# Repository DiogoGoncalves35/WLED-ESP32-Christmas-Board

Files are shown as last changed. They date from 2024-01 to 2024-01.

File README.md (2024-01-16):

# WLED ESP32 Christmas Board

  

This board is designed to control 4 x WS2812B string lights (Max 3A Total) via WLED software, and it was added a 4A fuse to protect. Max current for the 4 strings is about 3A, and 1A is left to ESP32.   



Board was tested with 2 x WS2812B 5 meter string lights, each draws arround 400-600 mA with color white and brightness at 100%. WLED version was [v0.14.0 "Hoshi"](https://github.com/Aircoookie/WLED/releases/tag/v0.14.0).

------------

### Schematic 

The [schematic](/PCB/Schematic.pdf) is arround ESP32 WROOM 32E microcontroller. A 4A fuse was added to protect the circuit in case of short circuit, the AMS1117 regulates the input voltage to 3.3V and powers the ESP32.

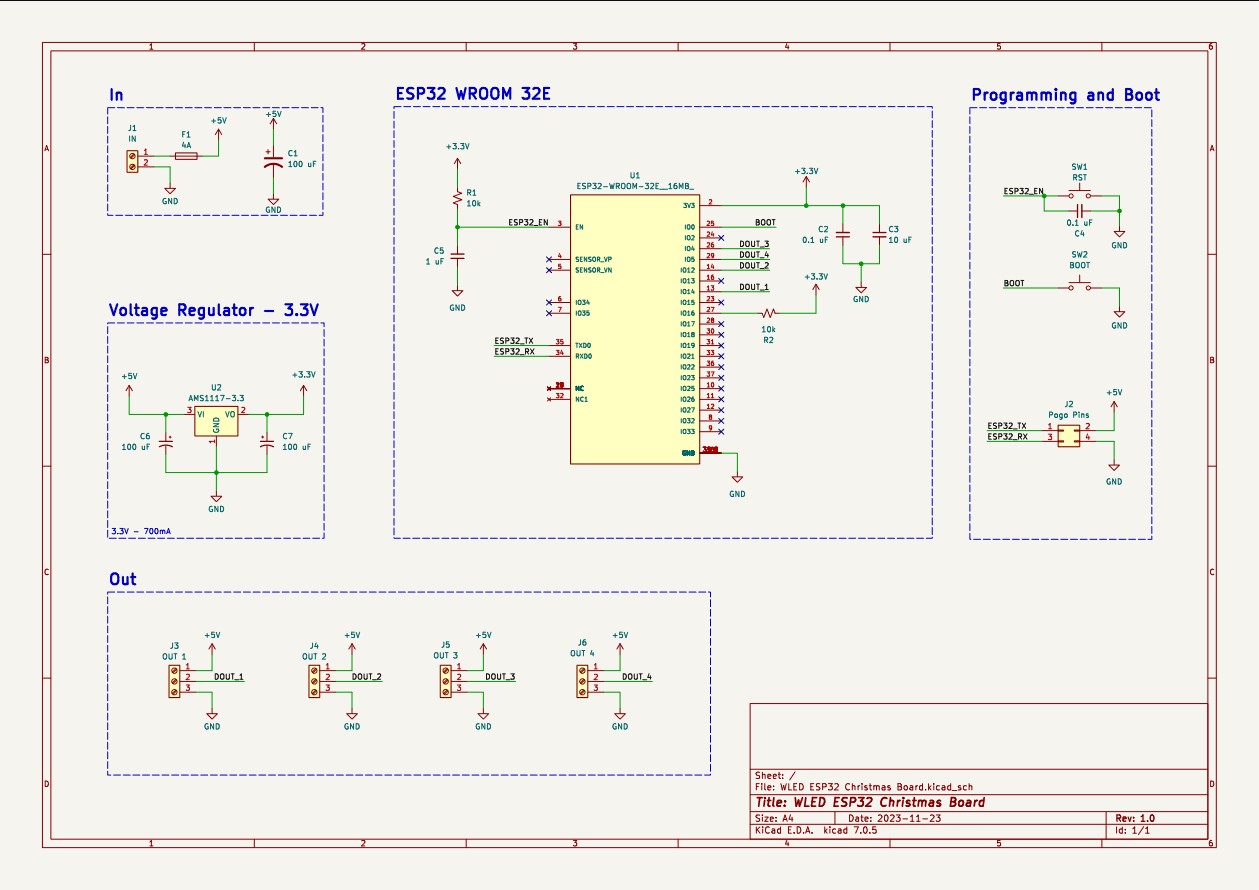
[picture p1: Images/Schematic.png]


------------

### PCB

[This](/PCB) 1.6mm board contains 4 layers with the stackup Signal+Power/GND/GND/Signal+Power.The connector on the right is for programming and it works with pogo pins.  

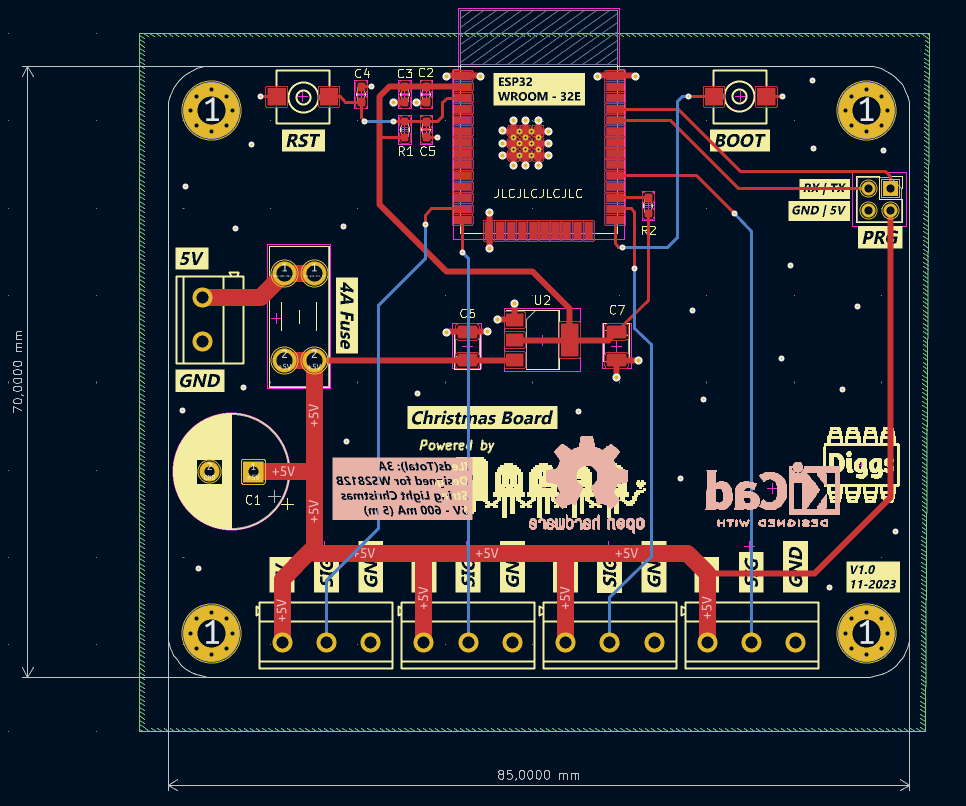
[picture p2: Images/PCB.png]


------------

### Known issues

- Some noise on TX/RX lines, sometimes [this](https://user-images.githubusercontent.com/64553282/108736433-e6be2380-7531-11eb-8186-5ca70f359cc5.PNG) appears and causes board to crash, by connecting pogo pins withot any connection to a programmer board fixed the issue

------------

### To-Do

- Fixing noise on TX/RX lines

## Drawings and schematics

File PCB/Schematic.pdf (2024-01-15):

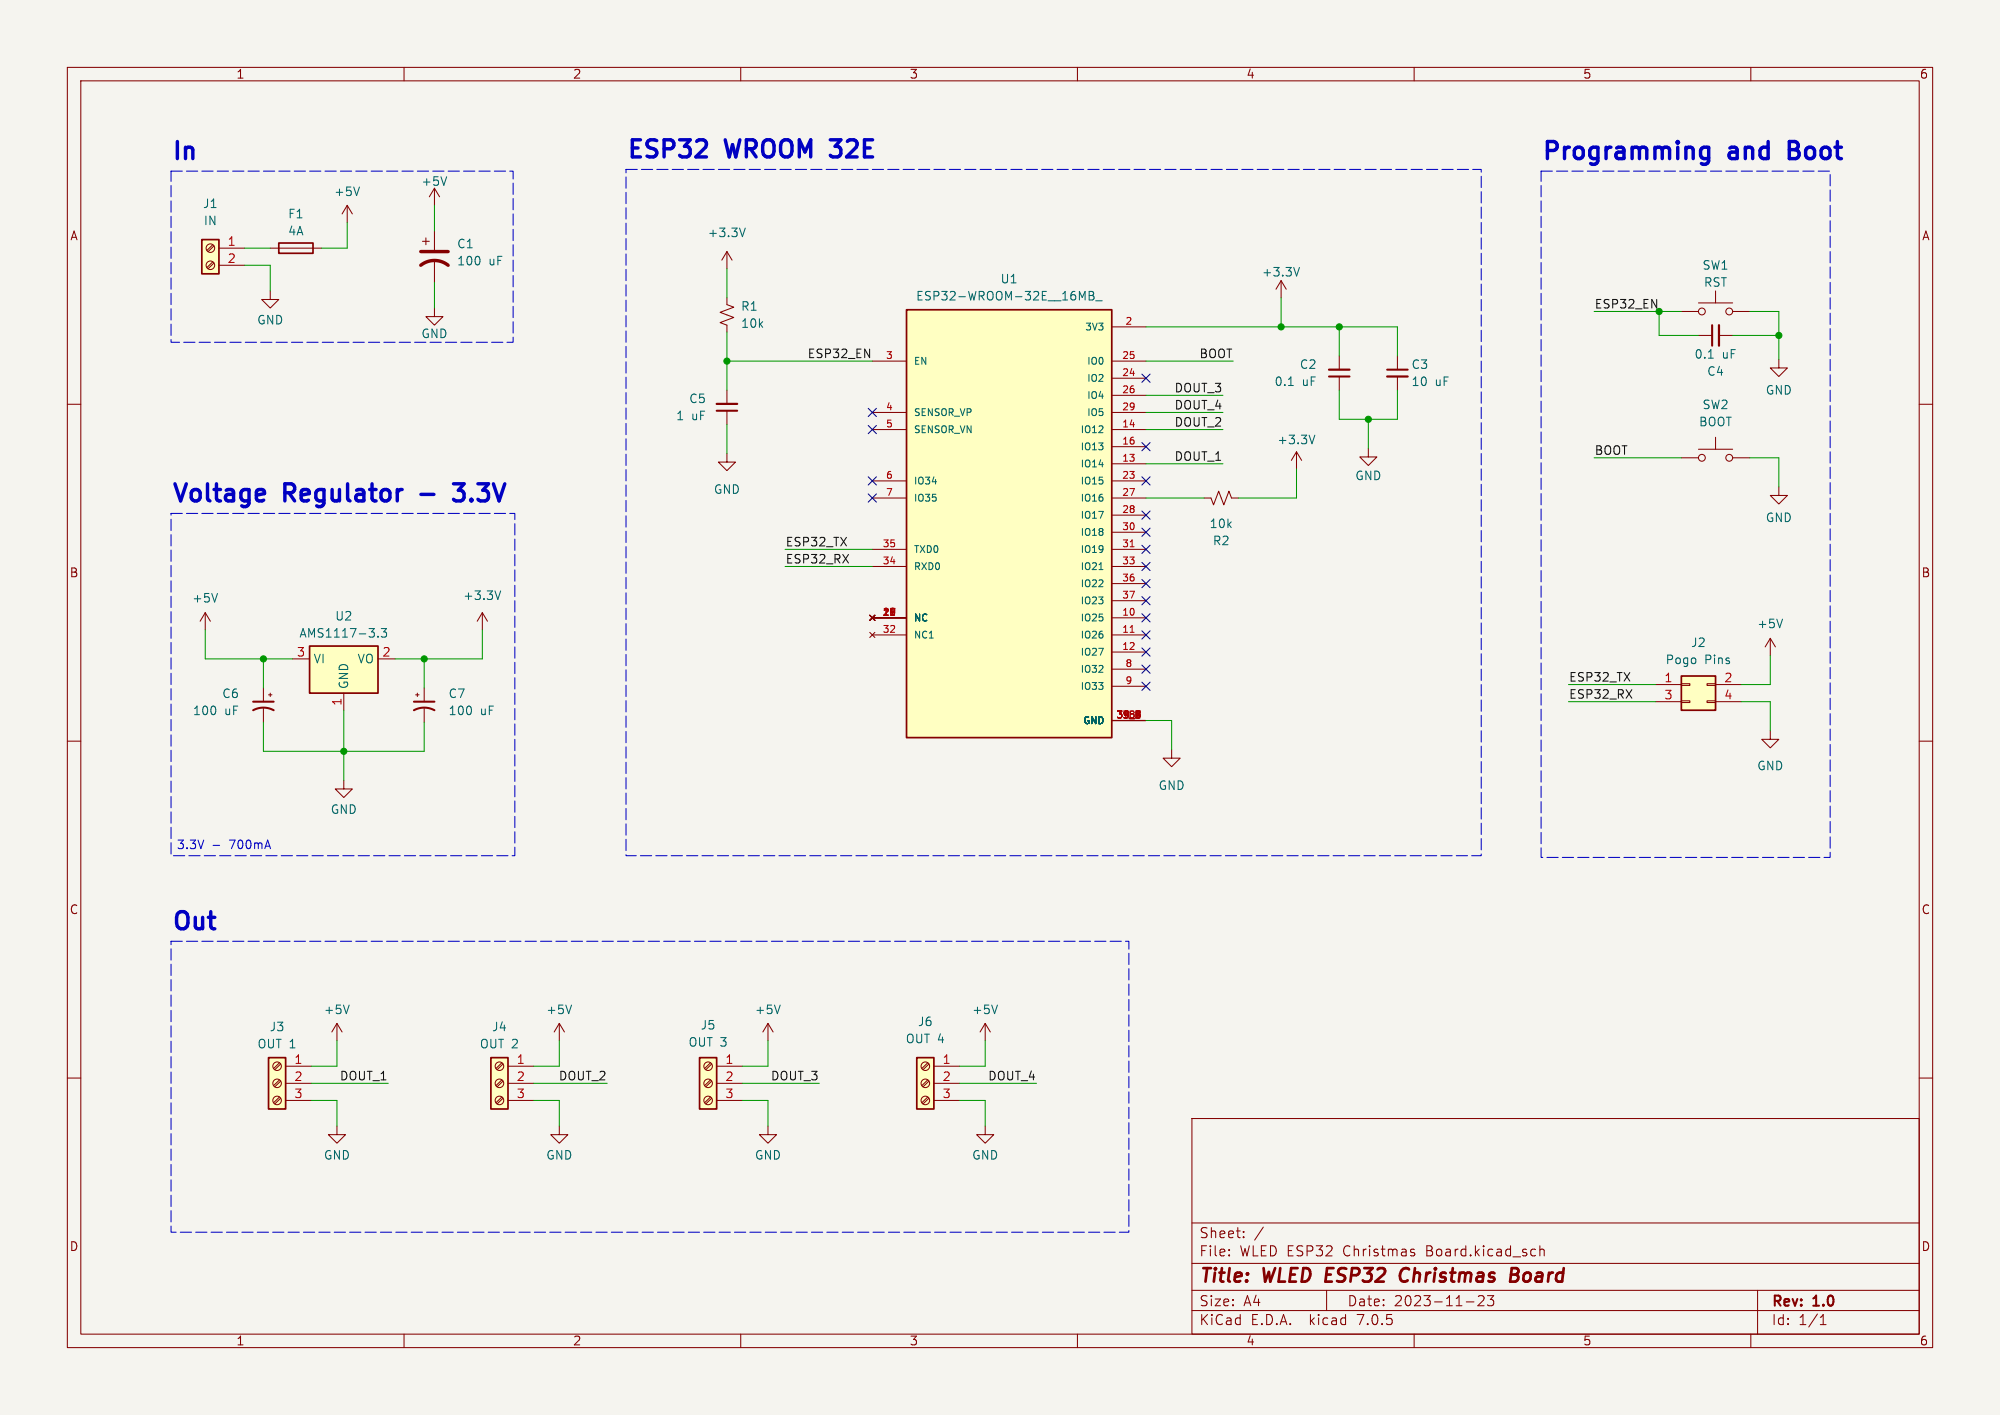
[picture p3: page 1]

Id: 1/1 Title: WLED ESP32 Christmas Board

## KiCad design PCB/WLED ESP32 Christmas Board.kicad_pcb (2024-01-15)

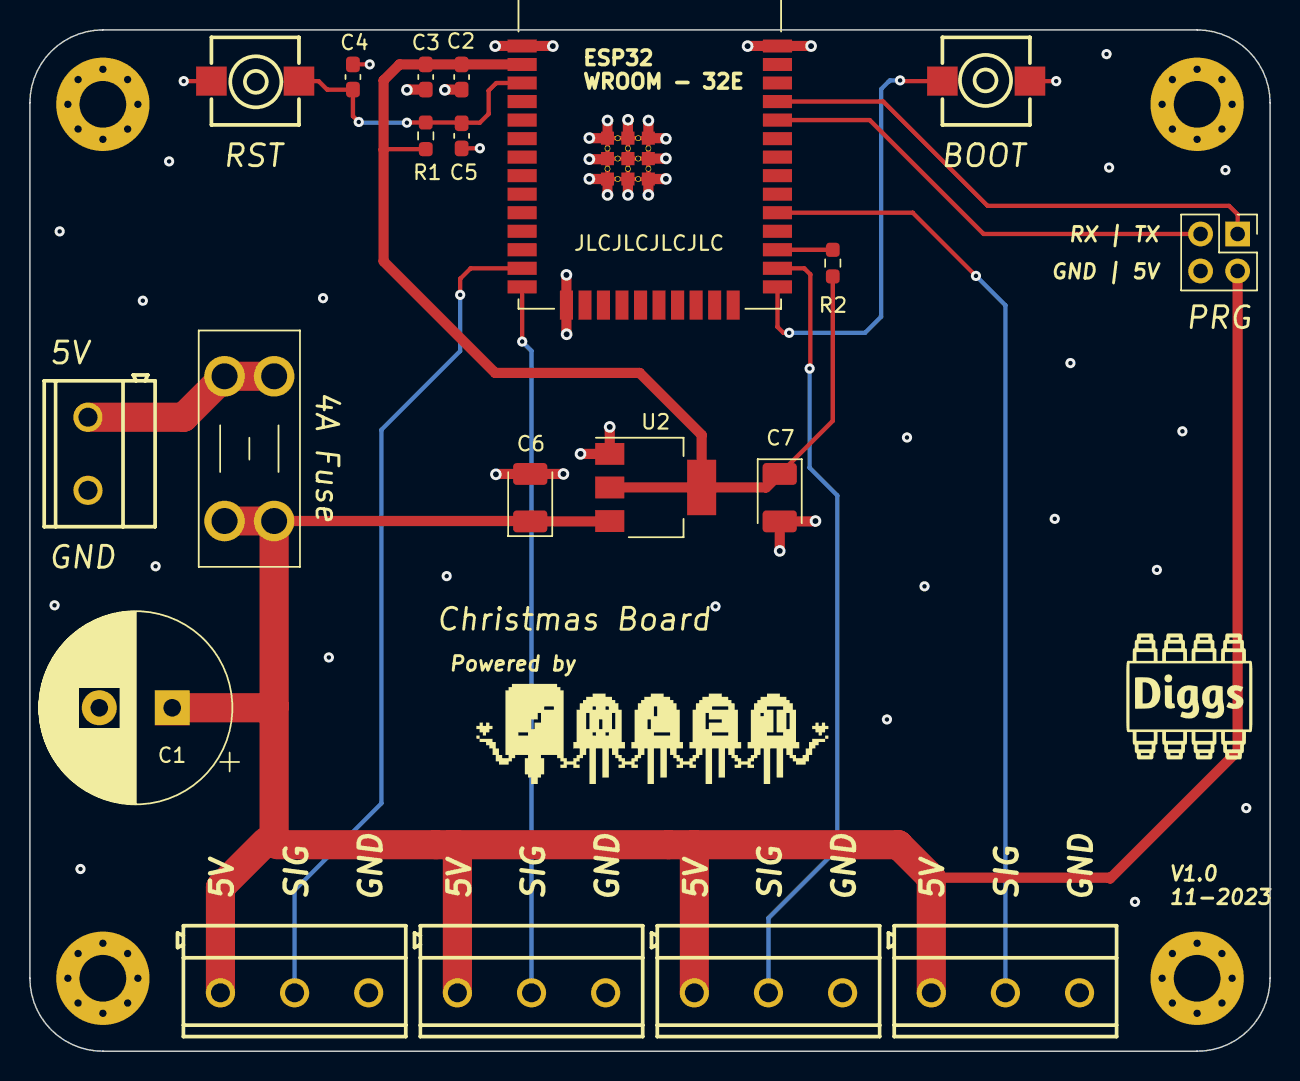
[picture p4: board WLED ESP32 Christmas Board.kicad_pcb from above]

Board: 4 copper layers, 85.0 x 70.0 mm, 20 parts (0 on the bottom side), 13 nets.

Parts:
C1: 100 uF; CP_Radial_D13.0mm_P5.00mm
C2, C4: 0.1 uF; C_0603_1608Metric_Pad1.08x0.95mm_HandSolder
C3: 10 uF; C_0603_1608Metric_Pad1.08x0.95mm_HandSolder
C5: 1 uF; C_0603_1608Metric_Pad1.08x0.95mm_HandSolder
C6, C7: 100 uF; CP_EIA-3528-21_Kemet-B_Pad1.50x2.35mm_HandSolder
F1: 4A; Fuseholder_Blade_Mini_Keystone_3568
J1: IN; 2P
J2: Pogo Pins; PinHeader_2x02_P2.54mm_Vertical
J3: OUT 1; 3P
J4: OUT 2; 3P
J5: OUT 3; 3P
J6: OUT 4; 3P
R1, R2: 10k; R_0603_1608Metric_Pad0.98x0.95mm_HandSolder
SW1: RST; SMD Switch
SW2: BOOT; SMD Switch
U1: ESP32WROOM-32E__16MB_; XCVR_ESP32-WROOM-32E__16MB_
U2: AMS1117-3.3; SOT-223-3_TabPin2

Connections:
+3.3V: C2.2, C3.1, C7.1, R1.1, R2.2, U1.2 (3V3), U2.2 (VO)
+5V: C1.1, C6.1, F1.2, J2.2, J3.1, J4.1, J5.1, J6.1, U2.3 (VI)
/BOOT: SW2.1, U1.25 (IO0)
/DOUT_1: J3.2, U1.13 (IO14)
/DOUT_2: J4.2, U1.14 (IO12)
/DOUT_3: J5.2, U1.26 (IO4)
/DOUT_4: J6.2, U1.29 (IO5)
/ESP32_EN: C4.1, C5.2, R1.2, SW1.1, U1.3 (EN)
/ESP32_RX: J2.3, U1.34 (RXD0)
/ESP32_TX: J2.1, U1.35 (TXD0)
GND: C1.2, C2.1, C3.2, C4.2, C5.1, C6.2, C7.2, J1.2, J2.4, J3.3, J4.3, J5.3, J6.3, SW1.2, SW2.2, U1.1 (GND), U1.15 (GND), U1.38 (GND), U1.39_1 (GND), U1.39_2 (GND), U1.39_3 (GND), U1.39_4 (GND), U1.39_5 (GND), U1.39_6 (GND), U1.39_7 (GND), U1.39_8 (GND), U1.39_9 (GND), U1.39_10, U1.39_11, U1.39_12, U1.39_13, U1.39_14, U1.39_15, U1.39_16, U1.39_17, U1.39_18, U1.39_19, U1.39_20, U1.39_21, U2.1 (GND)
unnamed: F1.1, J1.1
unnamed: R2.1, U1.27 (IO16)
